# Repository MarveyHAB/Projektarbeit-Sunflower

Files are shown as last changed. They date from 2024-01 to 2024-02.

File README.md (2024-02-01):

Willkommen im Sunflower GitHub Repository:
Sunflower_1

Sunflower_2

Solarblume_V2_Elektronikentwurf v5 test

Der Schaltplan:
Solarblume_V2_Elektronikentwurf v2

Pico W Pinout:
PicoW-A4-Pinout

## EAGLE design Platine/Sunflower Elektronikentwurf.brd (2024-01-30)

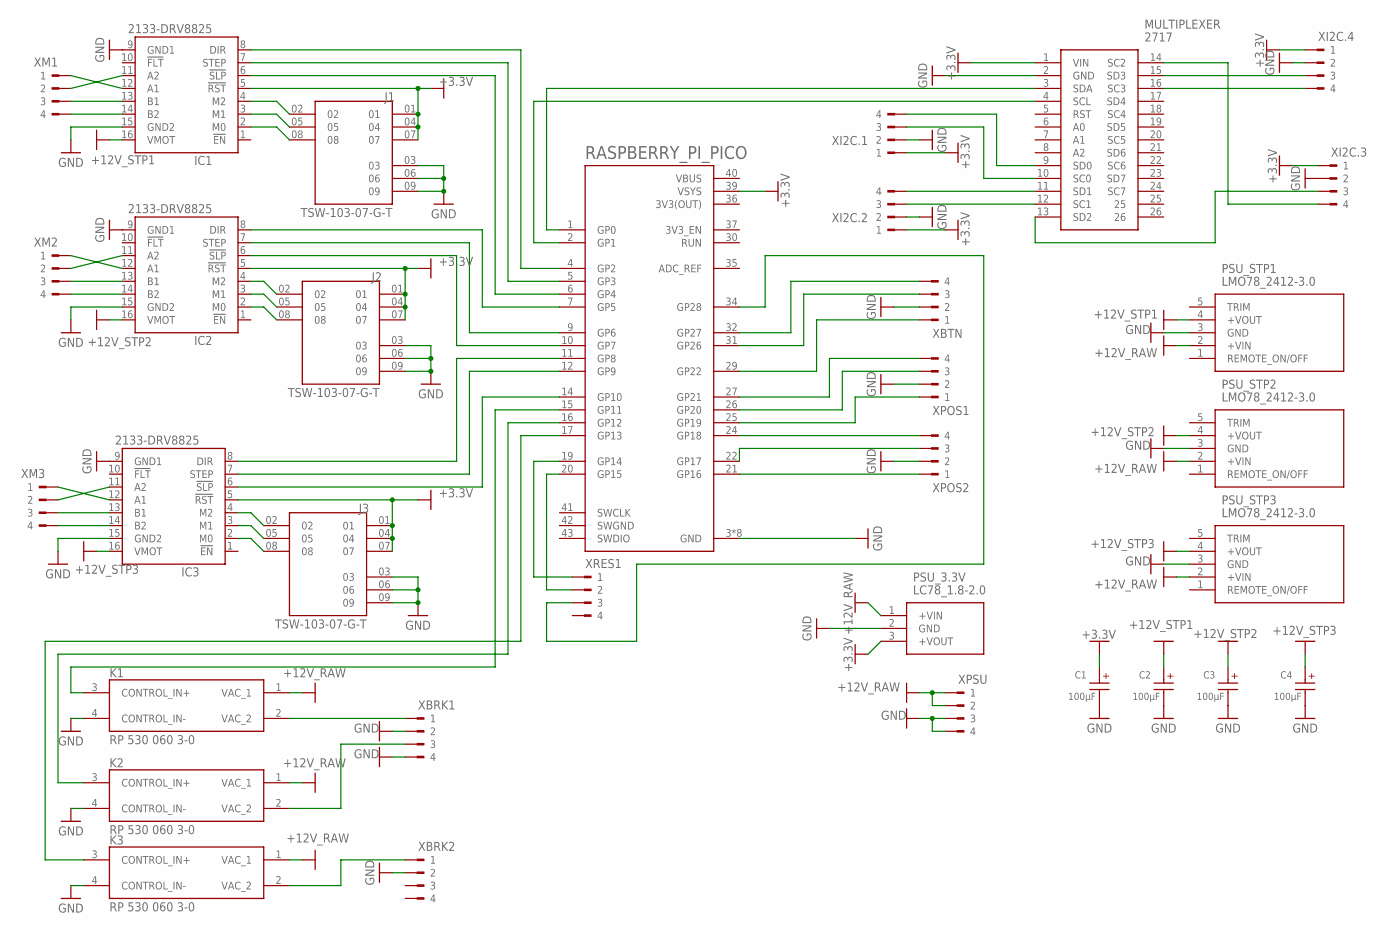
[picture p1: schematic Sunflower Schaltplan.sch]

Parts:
C1, C2, C3, C4: 100µF; WCAP-ATET_10X16(DXL)
IC1, IC2, IC3: 2133-DRV8825; DRV8825
J1, J2, J3: TSW-103-07-G-T; SAMTEC_TSW-103-07-G-T
K1, K2, K3: RP 530 060 3-0; RELAY_RP1A23D5
MULTIPLEXER: 2717
PSU_3.3V: LC78_1.8-2.0; LC78_1820; MANUFACTURER_PART_NUMBER LC78_03-2.0
PSU_STP1, PSU_STP2, PSU_STP3: LMO78_2412-3.0; LMO78_241230
RASPBERRY_PI_PICO: RASPBERRY_PICOTH; PICO-PKG-TH
XBRK1, XBRK2: ANLOX_PT09304HBBN
XBTN: ANLOX_PT09304HBBN
XI2C.1, XI2C.2, XI2C.3, XI2C.4: ANLOX_PT09304HBBN
XM1, XM2, XM3: ANLOX_PT09304HBBN
XPOS1, XPOS2: ANLOX_PT09304HBBN
XPSU: ANLOX_PT09304HBBN
XRES1: ANLOX_PT09304HBBN

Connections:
3V3(OUT): RASPBERRY_PI_PICO.36 (3V3(OUT))
+3.3V: C1.1 (+), IC1.5 (!RST), IC2.5 (!RST), IC3.5 (!RST), J1.01, J1.04, J1.07, J2.01, J2.04, J2.07, J3.01, J3.04, J3.07, MULTIPLEXER.1 (VIN), PSU_3.3V.3 (+VOUT), RASPBERRY_PI_PICO.39 (VSYS), XI2C.1.1, XI2C.2.1, XI2C.3.1, XI2C.4.1
+12V_RAW: K1.1 (VAC_1), K2.1 (VAC_1), K3.1 (VAC_1), PSU_3.3V.1 (+VIN), PSU_STP1.2 (+VIN), PSU_STP2.2 (+VIN), PSU_STP3.2 (+VIN), XPSU.1, XPSU.2
+12V_STP1: C2.1 (+), IC1.16 (VMOT), PSU_STP1.4 (+VOUT)
+12V_STP2: C3.1 (+), IC2.16 (VMOT), PSU_STP2.4 (+VOUT)
+12V_STP3: C4.1 (+), IC3.16 (VMOT), PSU_STP3.4 (+VOUT)
GND: C1.2 (-), C2.2 (-), C3.2 (-), C4.2 (-), IC1.9 (GND1), IC1.15 (GND2), IC2.9 (GND1), IC2.15 (GND2), IC3.9 (GND1), IC3.15 (GND2), J1.03, J1.06, J1.09, J2.03, J2.06, J2.09, J3.03, J3.06, J3.09, K1.4 (CONTROL_IN-), K2.4 (CONTROL_IN-), K3.4 (CONTROL_IN-), MULTIPLEXER.2 (GND), PSU_3.3V.2 (GND), PSU_STP1.3 (GND), PSU_STP2.3 (GND), PSU_STP3.3 (GND), RASPBERRY_PI_PICO.3 (GND), RASPBERRY_PI_PICO.8 (GND), RASPBERRY_PI_PICO.13 (GND), RASPBERRY_PI_PICO.18 (GND), RASPBERRY_PI_PICO.23 (GND), RASPBERRY_PI_PICO.28 (GND), RASPBERRY_PI_PICO.33 (GND), RASPBERRY_PI_PICO.38 (GND), XBRK1.2, XBRK1.4, XBRK2.2, XBTN.2, XI2C.1.2, XI2C.2.2, XI2C.3.2, XI2C.4.2, XPOS1.2, XPOS2.2, XPSU.3, XPSU.4
unnamed: MULTIPLEXER.3 (SDA), RASPBERRY_PI_PICO.1 (GP0)
unnamed: MULTIPLEXER.4 (SCL), RASPBERRY_PI_PICO.2 (GP1)
unnamed: IC1.12 (A1), XM1.1
unnamed: IC1.11 (A2), XM1.2
unnamed: IC1.13 (B1), XM1.3
unnamed: IC1.14 (B2), XM1.4
unnamed: IC2.12 (A1), XM2.1
unnamed: IC2.11 (A2), XM2.2
unnamed: IC2.13 (B1), XM2.3
unnamed: IC2.14 (B2), XM2.4
unnamed: IC3.12 (A1), XM3.1
unnamed: IC3.11 (A2), XM3.2
unnamed: IC3.13 (B1), XM3.3
unnamed: IC3.14 (B2), XM3.4
unnamed: IC1.8 (DIR), RASPBERRY_PI_PICO.4 (GP2)
unnamed: IC2.8 (DIR), RASPBERRY_PI_PICO.7 (GP5)
unnamed: IC3.8 (DIR), RASPBERRY_PI_PICO.11 (GP8)
unnamed: IC1.7 (STEP), RASPBERRY_PI_PICO.5 (GP3)
unnamed: IC2.7 (STEP), RASPBERRY_PI_PICO.9 (GP6)
unnamed: IC1.4 (M2), J1.02
unnamed: RASPBERRY_PI_PICO.29 (GP22), XBTN.1
unnamed: RASPBERRY_PI_PICO.31 (GP26), XBTN.3
unnamed: RASPBERRY_PI_PICO.32 (GP27), XBTN.4
unnamed: MULTIPLEXER.9 (SD0), XI2C.1.4
unnamed: MULTIPLEXER.10 (SC0), XI2C.1.3
unnamed: MULTIPLEXER.11 (SD1), XI2C.2.4
unnamed: MULTIPLEXER.12 (SC1), XI2C.2.3
unnamed: MULTIPLEXER.13 (SD2), XI2C.3.3
unnamed: MULTIPLEXER.15 (SD3), XI2C.4.3
unnamed: MULTIPLEXER.14 (SC2), XI2C.3.4
unnamed: MULTIPLEXER.16 (SC3), XI2C.4.4
unnamed: RASPBERRY_PI_PICO.21 (GP16), XPOS2.1
unnamed: RASPBERRY_PI_PICO.22 (GP17), XPOS2.3
unnamed: RASPBERRY_PI_PICO.24 (GP18), XPOS2.4
unnamed: RASPBERRY_PI_PICO.25 (GP19), XPOS1.1
unnamed: RASPBERRY_PI_PICO.26 (GP20), XPOS1.3
unnamed: RASPBERRY_PI_PICO.27 (GP21), XPOS1.4
unnamed: K1.3 (CONTROL_IN+), RASPBERRY_PI_PICO.15 (GP11)
unnamed: K2.3 (CONTROL_IN+), RASPBERRY_PI_PICO.16 (GP12)
unnamed: K3.3 (CONTROL_IN+), RASPBERRY_PI_PICO.17 (GP13)
unnamed: K3.2 (VAC_2), XBRK2.1
unnamed: RASPBERRY_PI_PICO.20 (GP15), XRES1.2
unnamed: RASPBERRY_PI_PICO.19 (GP14), XRES1.1
unnamed: IC3.6 (!SLP), RASPBERRY_PI_PICO.14 (GP10)
unnamed: IC2.6 (!SLP), RASPBERRY_PI_PICO.10 (GP7)
unnamed: K1.2 (VAC_2), XBRK1.1
unnamed: K2.2 (VAC_2), XBRK1.3
unnamed: IC1.6 (!SLP), RASPBERRY_PI_PICO.6 (GP4)
unnamed: RASPBERRY_PI_PICO.34 (GP28), XRES1.3
unnamed: IC1.3 (M1), J1.05
unnamed: IC3.7 (STEP), RASPBERRY_PI_PICO.12 (GP9)
unnamed: IC1.2 (M0), J1.08
unnamed: IC2.4 (M2), J2.02
unnamed: IC2.3 (M1), J2.05
unnamed: IC2.2 (M0), J2.08
unnamed: IC3.4 (M2), J3.02
unnamed: IC3.3 (M1), J3.05
unnamed: IC3.2 (M0), J3.08
SWGND: RASPBERRY_PI_PICO.42 (SWGND)
VBUS: RASPBERRY_PI_PICO.40 (VBUS)

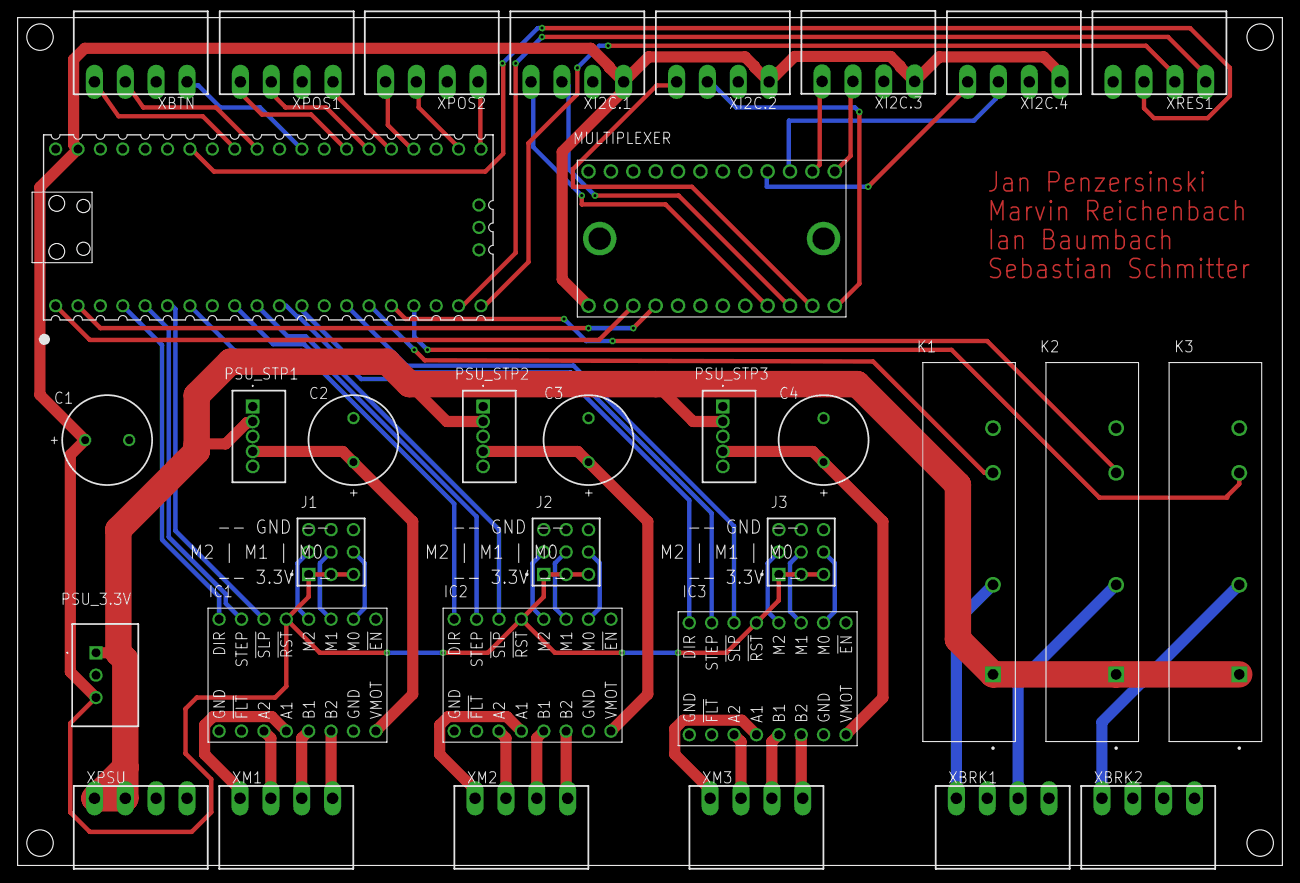
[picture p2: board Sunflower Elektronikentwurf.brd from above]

Board: 2 copper layers, 143.5 x 96.2 mm, 33 parts (0 on the bottom side), 64 nets.

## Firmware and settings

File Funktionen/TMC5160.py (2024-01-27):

# TMC5160 Driver
# By Ben Jackson


# Wiring:
# Pico      -    TMC5160
# SPIO-RX   -    DO     (4.7K pullup)
# SPIO-TX   -    DI
# SPIO-CSK  -    CLK
# 15        -    CS
# 


from machine import SPI, Pin
import time, math


class TMC5160:

    # Registers
    GCONF = 0x00
    GSTAT = 0X01
    DRV_CONF = 0X0A
    GLOBALSCALER = 0X0B
    IHOLD_IRUN = 0X10
    TPOWERDOWN = 0X11
    TPWMTHRS = 0X13
    RAMPMODE = 0X20
    XACTUAL = 0X21
    VACTUAL = 0X22
    VSTART = 0X23
    TZEROWAIT = 0X2C
    XTARGET = 0X2D
    SW_MODE = 0X34
    RAMP_STAT = 0X35
    A1 = 0X24
    V1 = 0X25
    AMAX = 0X26
    VMAX = 0X27
    DMAX = 0X28
    D1 = 0X2A
    VSTOP = 0X2B
    CHOPCONF = 0X6C

    chopBaseVal = 0      # The first 24 bits of CHOPCONF
    microStepVal = 0x0
    microStep = 256

    MicroStep256 = (256, 0x0)
    MicroStep128 = (128, 0x1)
    MicroStep64 = (64, 0x2)
    MicroStep32 = (32, 0x3)
    MicroStep16 = (16, 0x4)
    MicroStep8 = (8, 0x5)
    MicroStep4 = (4, 0x6)
    MicroStep2 = (2, 0x7)
    MicroStep1 = (1, 0x8)



    maxCurrent = 3  # Max contiuous current capabilty of the board in Amps


    def __init__(self, spiObj: SPI, csPin: int, debug=0):
        """Initialise

        Args:
            spiObj (SPI): The SPI object to use.
            csPin (int): The cs pin number
            debug (int, optional): Enable debug. Defaults to 0.
        """

        self.cs = Pin(csPin, Pin.OUT)
        self.cs.high()

        self.spi = spiObj
        self.debug = debug

        self.writeReg(self.GCONF, 0x04)             # enable PWM mode
        self.setChopperConfig(3, 0, 13, 2, 0, False)
        self.writeReg(self.TPWMTHRS, 0x1F4)         # using the example value of 500


    def intToTwosComp(self, val, nbits):
        """Compute the 2's complement of int value val 

        Args:
            val (int): Signed Integer to convert
            nbits (int): The number of bits for the converted value

        Returns:
            int: an int that represents the raw twos complement
        """
        if val < 0:
            val = (1 << nbits) + val
        else:
            if (val & (1 << (nbits - 1))) != 0:
                # If sign bit is set.
                # compute negative value.
                val = val - (1 << nbits)
        return val


    def TwosComp2Int(self, val, nbits) -> int:
        """Compute an Integer (signed or unsigned) from a raw int (converted from bytearray)

        Args:
            val (int): Raw conversion from bytearray or bytes

        Returns:
            int: signed integer
        """
        if val & 2**(nbits-1) > 0:
            return val - 2**nbits
        else:
            return val


    def writeReg(self, address: int, value: int, signed=False):
        """Write to a register.  Can write to a signed register.

        Args:
            address (int): The address to write to.
            value (int): The value to write
            signed (bool, optional): Convert the value to a two's compliment signed integer. Defaults to False.

        Returns:
            int: Status of the write
        """
        rb = bytearray(5)       # buffer for the data we get back
        if signed:
            value = self.intToTwosComp(value, 32)

        data = 0x80             # first bit indicates a write.  
        data = address | data   # add in the address
        data = data << 32
        data = data | value

        self.cs.low()
        self.spi.write_readinto(data.to_bytes(5, 'big'), rb)
        self.cs.high()

        if self.debug >= 4: print("Write Reg:", data.to_bytes(5, 'big'))  # .to_bytes(5, 'big', signed=False)
        if self.debug >= 4: print("       rb:", rb)
        if self.debug >= 4: print("    status:", rb[0] & 0b10)

        return rb[0] & 0b10     # return the status.


    def readReg(self, address: int, signed=False):
        """Read a register.  Can convert a signed integer value.

        Args:
            address (int): The address to read
            signed (bool, optional): Converts a two's compliment number. Defaults to False.

        Returns:
            tuple: The value read from the register and the status.
        """
        rb = bytearray(5)       # buffer for the data we get back
        data = address << 32

        self.cs.low()
        self.spi.write_readinto(data.to_bytes(5, 'big'), rb)
        self.cs.high()
        self.cs.low()
        self.spi.write_readinto(data.to_bytes(5, 'big'), rb)
        self.cs.high()

        if self.debug >= 3: print(" Read Reg address:", hex(address))  # .to_bytes(5, 'big', signed=False)
        if self.debug >= 3: print("       rb:", rb)
        if self.debug >= 2: print("    status:", rb[0] & 0b10)

        status = int.from_bytes(rb, 'big') >> 32

        if signed:
            return self.TwosComp2Int(int.from_bytes(rb, 'big')  & 0xFFFFFFFF, 32), status
        else:
            return int.from_bytes(rb, 'big')  & 0xFFFFFFFF, status


    def setCurrent(self, current: float, idlePercent: float):
        """Set the max current via the globalscaler.

        Args:
            current (float): In Amps
            idlePercent (float): 0->100
        """
        if current > self.maxCurrent:
            raise AttributeError("Current exceeds board capability")
        if idlePercent > 100 or idlePercent < 0:
            raise AttributeError("Idle Current Percentage must be between 0 and 100")

        # set the glocal current scale
        m = 255/self.maxCurrent
        gs = int(math.floor((current * m)))
        self.writeReg(self.GLOBALSCALER, gs)

        # set the I_RUN and I_HOLD
        iHold = int(math.floor(((idlePercent/100) * 32) -1))
        iHold_iRun_value = iHold | (31 << 8) | (0x6 <<16)
        self.writeReg(self.IHOLD_IRUN, iHold_iRun_value)

        # set TPOWERDOWN to default (10)
        self.writeReg(self.TPOWERDOWN, 0x0A)


    def setRamp(self, vstart: int, a1: int, v1: int, amax: int, vmax: int, dmax: int, d1: int, vstop: int):
        """Configure the Ramp parameters

        Args:
            vstart (int): register value
            a1 (int): register value
            v1 (int): register value
            amax (int): register value
            vmax (int): register value
            dmax (int): register value
            d1 (int): register value
            vstop (int): register value
        """
        assert 0 <= vstart <= 0x3FFFF,      "vstart is out or range"
        assert 0 <= a1 <= 0xFFFF,           "a1 is out of range"
        assert 0 <= v1 <= 0xFFFFF,          "v1 is out of range"
        assert 0 <= amax <= 0xFFFF,         "amax is out of range"
        assert 0 <= vmax <= 0x7FFFFF,       "vmax is out of range"
        assert 0 <= dmax <= 0xFFFF,         "dmax is out of range"
        assert 0 <= d1 <= 0xFFFF,           "d1 is out of range"
        assert 0 <= vstop <= 0x3FFFF,       "vstop is out of range"

        self.writeReg(self.VSTART, vstart)
        self.writeReg(self.A1, a1)
        self.writeReg(self.V1, v1)
        self.writeReg(self.AMAX, amax)
        self.writeReg(self.VMAX, vmax)
        self.writeReg(self.DMAX, dmax)
        self.writeReg(self.D1, d1)
        self.writeReg(self.VSTOP, vstop)
        self.writeReg(self.RAMPMODE, 0x00)


    def setAutoRamp(self, speed: int, accel: int):
        """Configure a simple ramp

        Args:
            speed (int): the max speed
            accel (int): general acceleration value
        """
        self.setRamp(vstart=0, a1=accel, v1=int(speed/2), amax=int(accel/2), vmax=speed, \
                    dmax=int((accel*1.5)/2), d1=int(accel*1.5), vstop=10)  


    def moveToPos(self, pos: int):
        """Move the motor to a specific position.  

        Args:
            pos (int): the position in (micro)steps

        Returns:
            int: status (1 = error)
        """
        if pos < -2147483648 or pos > 2147483648:
            raise AttributeError("Target postition out of range")
        return self.writeReg(self.XTARGET, pos, True) 


    def getPos(self):
        """Read the current motor position

        Returns:
            int: the position in (micro)steps
        """
        return self.readReg(self.XACTUAL, True)[0]


    def getStatus(self):
        """Read the current driver status

        Returns:
            dict: Dictionary of status values
        """
        x = self.readReg(self.XACTUAL, True)
        status = x[1]
        position = x[0]

        positionReached = bool(status & 0b00100000)
        velocityReached = bool(status & 0b00010000)
        standstill      = bool(status & 0b00001000)
        sg2             = bool(status & 0b00000100)
        driverError     = bool(status & 0b00000010)
        resetFlag       = bool(status & 0b00000001)

        statDict = {
            'positionReached': positionReached,
            'velocityReached': velocityReached,
            'standStill': standstill,
            'sg2': sg2,
            'driverError': driverError,
            'resetFlag': resetFlag,
            'position': position
            }
        return statDict


    def disable(self):
        """Disable the motor
        """
        #self.writeReg(self.CHOPCONF, 0x050100C0)
        self.writeReg(self.CHOPCONF, (self.chopBaseVal  & 0xFFFFF0) | (self.microStepVal << 24))
    

    def enable(self):
        """Enable the motor
        """
        self.writeReg(self.CHOPCONF, self.chopBaseVal  | (self.microStepVal << 24))
        #self.writeReg(self.CHOPCONF, 0x050100C3)

    def setStepMode(self, msMode: tuple):
        """Set the Microstepping mode

        Args:
            msMode (Microstep tupple values): eg: self.MicroStep256
        """
        self.microStepVal = msMode[1]
        self.microStep = msMode[0]
        self.writeReg(self.CHOPCONF, self.chopBaseVal  | (self.microStepVal << 24))

    def setHomePosition(self):
        """Set the current motor postion to 0
        """
        self.writeReg(self.XACTUAL, 0)


    def configHoming(self, softStop, enableLeft, enableRight, invertLeft=False, invertRight=False):
        """Set the parameters for the limit switches

        Args:
            softStop (bool): True = Soft Stop, False = Hard Stop (Emergency stop)
            enableLeft (bool): enable the left limit switch
            enableRight (bool): enable the right limit switch
            invertLeft (bool, optional): Reverse the polarity of the left switch. Defaults to False.
            invertRight (bool, optional): Reverse the polarity of the right switch. Defaults to False.
        """
        data = int(softStop) << 11
        data = (int(invertLeft) << 2) | data
        data = (int(invertRight) << 3) | data
        data = int(enableLeft) | data
        data = (int(enableRight) << 1) | data

        self.writeReg(self.SW_MODE, data)


    def setChopperConfig(self, tOff: int, hStart: int, hEnd: int, tbl: int, tpfd: int, vHigh=False):
        """Set the Chopper Configuration Parameters. Chopper mode is always set to SpreadCycle (0). See the data sheet for full explaniations. 

        Args:   
            tOff (int): off time setting.
            hStart (int): hysteresis start value.
            hEnd (int): hysteresis end value.
            tbl (int): blank time select.
            tpfd (int): passive fast decay time.
            vHigh (bool, optional): Enable high velicity settings. Defaults to False.
        """
        assert 2 <= tOff <= 15,     "tOff Out of range: 2->15"
        assert 0 <= hStart <= 7,    "hStart Out of range: 0->7"
        assert 0 <= hEnd <= 15,     "hEnd Out of range: 0->15"
        assert 0 <= tbl <= 3,       "tbl Out of range: 0->3"
        assert 0 <= tpfd <= 15,     "tpfd Out of range: 0->15"
        
        ccVal = tOff
        ccVal = (hStart << 4) + ccVal
        ccVal = (hEnd << 7) + ccVal
        ccVal = (tbl << 15) + ccVal
        ccVal = (tpfd << 20) + ccVal
        if vHigh:               # enable vhighchm and vhighfs
            ccVal = (3 << 18) + ccVal
        ccVal = (self.microStepVal << 24) + ccVal

        self.chopBaseVal = ccVal
        self.writeReg(self.CHOPCONF, self.chopBaseVal) 






if __name__ == "__main__":
    """Testing Routine
    """
        
    print("Starting...")

    led = Pin(25, Pin.OUT)
    led.low()

    #spi = SPI(0)
    spi = SPI(0, baudrate=4000000, bits=8, firstbit=SPI.MSB, sck=Pin(18), mosi=Pin(19), miso=Pin(16))
    PSU24V  = Pin(12 , Pin.OUT, value=1)

    stepperA = TMC5160(spi, 28, 0)

    stepperA.enable()
    stepperA.setCurrent(2.8, 70)
    print(stepperA.getStatus())
    stepperA.setStepMode(stepperA.MicroStep1)

    
    # Homing to the left switch
    stepperA.setAutoRamp(speed=20000, accel=8000)           # set homing speed
    stepperA.configHoming(softStop=True,  enableLeft=True, enableRight=True, invertLeft=True, invertRight=True)     # setup the hoping options
    stepperA.moveToPos(-51200 * 50)                          # start the homing move negative is to left
    time.sleep_ms(10)                                       # Give the motor time to get moving
    while stepperA.getStatus()['standStill'] == False:
        time.sleep_ms(5)

    print("HOME FOUND")
    stepperA.setHomePosition()
    stepperA.moveToPos(0)                                    # cancel the rest of the move

    time.sleep(1)
     

    # Do a general move
    stepperA.setAutoRamp(speed=700000, accel=8000) 
    
    stepperA.moveToPos(200 * stepperA.microStep * 100)
    while stepperA.getStatus()['positionReached'] == False:
        time.sleep_ms(1)
        if stepperA.getStatus()['velocityReached']:  led.high()          # turn on the LED once the motor gets to full speed
        else: led.low()
    time.sleep(1)
    
    print(stepperA.getStatus())
    stepperA.moveToPos(0)
    while stepperA.getStatus()['positionReached'] == False:
        time.sleep_ms(1)
        if stepperA.getStatus()['velocityReached']:  led.high()          # turn on the LED once the motor gets to full speed
        else: led.low()

    print(stepperA.getStatus())


    #time.sleep(5)
    print(stepperA.readReg(stepperA.CHOPCONF))
    
    stepperA.disable()

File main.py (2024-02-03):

from sh1106     import SH1106_I2C
from _thread    import allocate_lock
from drehen     import drehen_grundpos, drehen_sonne, drehen_kali
from neigen     import neigen0, neigen90, neigen_sonne, neigen_kali
from faechern   import auffaechern, einfaechern, faechern_kali
from machine	import Pin, I2C
from time       import sleep, ticks_ms
from RTC        import sync_RTC_Pico_time
from Sonne      import getSEA
from errorcode  import fehlermeldung
from kompass    import QMC5883L
#Zeit mit RTC sync
sync_RTC_Pico_time()

#Display
i2c 	= I2C(0, scl=Pin(1), sda=Pin(0))
display	= SH1106_I2C(128, 64, i2c, Pin(28), 0x3c)

display.sleep(False)
display.fill(0)
display.text('Sunflower '  , 30, 20, 1)
display.text('ist bereit!', 20, 30, 1)
display.show()

#Kompass
kompass = QMC5883L(i2c)

#Allocate Lock
NOTHALT = allocate_lock()

#BTN
btn_startstopp	= Pin(27 , Pin.IN,Pin.PULL_UP)
btn_NOTHALT		= Pin(26 , Pin.IN,Pin.PULL_UP)

#State
fehler				= 0
ausrichten_freigabe	= False
anlage_ein        	= False
anlage_ist_aus		= True
state_1 			= True 
state_2 			= False 
state_3 			= False
state_4 			= False
state_5 			= False
state_6 			= False
state_7 			= False
state_8 			= False
state_9 			= False
state_10			= False
state_11			= False
state_12			= False
state_13			= False
state_14			= False

#BTN entprellen
push_ein_aus 		= 0
push_ein_aus_old 	= ticks_ms()

push_nothalt 		= 0
push_nothalt_old 	= ticks_ms()

quittieren			= 0

#Speicher Positionen
pos_neigen 			= 0
pos_drehen 			= 0

#Zeit zum Automtischen ausrichten in sek.
zeitabstand_ausrichten = 120

def ISR_ein_aus(pin27):
    global anlage_ein, fehler, NOTHALT, push_ein_aus, push_ein_aus_old, quittieren, state_1, state_2, state_3, state_4, state_5, state_6, state_7, state_8, state_9, state_10, state_11, state_12, state_13, state_14
    push_ein_aus_old = push_ein_aus
    push_ein_aus = ticks_ms()
    
    if (push_ein_aus - push_ein_aus_old) > 500:
        
        if fehler == 0 and NOTHALT.locked() == False:
            anlage_ein = not anlage_ein
        #Fehler Quittieren
        elif fehler != 0 or NOTHALT.locked() != False:
            quittieren += 1
            if quittieren == 2:
                NOTHALT.release()
            
                fehler		= 0
                quittieren	= 0
                
                display.fill(0)
                display.text('Fehler wurde '    , 0,  0, 1)
                display.text('qittiert.'       , 0, 10, 1)
                display.text('Sunflower'        , 0, 20, 1)
                display.text('referenziert neu!', 0, 30, 1)
                display.show()
                
                anlage_ein = True
                state_1 = True 
                state_2 = False 
                state_3 = False
                state_4 = False
                state_5 = False
                state_6 = False
                state_7 = False
                state_8 = False
                state_9 = False
                state_10= False
                state_11= False
                state_12= False
                state_13= False
                state_14= False
                
                sleep(2)
        
            
def ISR_NOTHALT(pin26):
    global NOTHALT, fehler, anlage_ein, push_nothalt, push_nothalt_old, state_1, state_2, state_3, state_4, state_5, state_6, state_7, state_8, state_9, state_10, state_11, state_12, state_13, state_14
    push_nothalt_old = push_nothalt
    push_nothalt = ticks_ms()
    
    if (push_nothalt - push_nothalt_old) > 250 and NOTHALT.locked() == False:
        anlage_ein	= False
        fehler 		= 41
        state_1 	= False   
        state_2 	= False 
        state_3 	= False
        state_4 	= False
        state_5 	= False
        state_6 	= False
        state_7 	= False
        state_8 	= False
        state_9 	= False
        state_10	= False
        state_11	= False
        state_12	= False
        state_13	= False
        state_14	= False
        NOTHALT.acquire()
        return
    else:
        return

btn_startstopp.irq(trigger=Pin.IRQ_RISING, handler=ISR_ein_aus)
btn_NOTHALT.irq(trigger=Pin.IRQ_RISING, handler=ISR_NOTHALT)



while True:
    sonnen_pos = getSEA(51,7,2)
    
    #Wird nur ausgefürt nach Hardreset oder NOTHALT oder Fehler!
    if state_1 == True and NOTHALT.locked() == False and anlage_ein == True:
        display.fill(0)
        display.text('Referenzieren', 0, 0, 1)
        display.text('neigen laeuft', 0, 10, 1)
        display.show()
        rueckgabe_neigen = neigen_kali(NOTHALT)
        if rueckgabe_neigen[0]!= 0:
            fehler 			= rueckgabe_neigen[0]
            analge_ein 		= False
            state_1			= False
        else:
            state_1 		= False
            state_2 		= True
            anlage_ist_aus 	= False
            pos_neigen 		= rueckgabe_neigen[1]
                
    if state_2 == True and NOTHALT.locked() == False and fehler == 0:
        display.fill(0)
        display.text('Referenzieren'    , 0, 0, 1)
        display.text('faechern laeuft', 0, 10, 1)
        display.show()
        if faechern_kali(NOTHALT) != 0:
            fehler 		= faechern_kali
            analge_ein 	= False
            state_2 	= False
        else:
            state_2 	= False
            state_3 	= True
    
    if state_3 == True and NOTHALT.locked() == False and fehler == 0:
        display.fill(0)
        display.text('Referenzieren'    , 0, 0, 1)
        display.text('drehen laeuft', 0, 10, 1)
        display.show()
        rueckgabe_drehen = drehen_kali(NOTHALT)
        if rueckgabe_drehen[0] != 0:
            fehler 		= rueckgabe_drehen[0]
            analge_ein 	= False
            state_3 	= False
        else:
            if sonnen_pos >0:
                state_3 	= False
                state_4 	= True
                a=kompass.axesAverage(100)
                kompass_az=int(kompass.calcAngle(a[0],a[1]))
                print("state 3 sonne oben gut")
            else:
                analge_ein 	= False
                state_3 	= False
                state_11 	= True
                print("Sonne unten")
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

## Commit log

2023-10-09 Update drehen_ohne_kompass.py
    Bug fixes
    [drehen_ohne_kompass.py]
2024-01-08 Update main.py
    erster aufruf der funktionen beim buttondruck
2024-01-22 Update main.py
    ohne timer interrupt
2024-02-03 Update neigen.py
    schreibfehler behoben
    [neigen.py]

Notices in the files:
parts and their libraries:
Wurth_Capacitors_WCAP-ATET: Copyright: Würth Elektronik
